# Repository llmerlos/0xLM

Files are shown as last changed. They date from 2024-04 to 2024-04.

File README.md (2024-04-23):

# PICCTRL - 0xLM
## 3x6 + 3 Split Ortholinear Keyboard with on board MCU
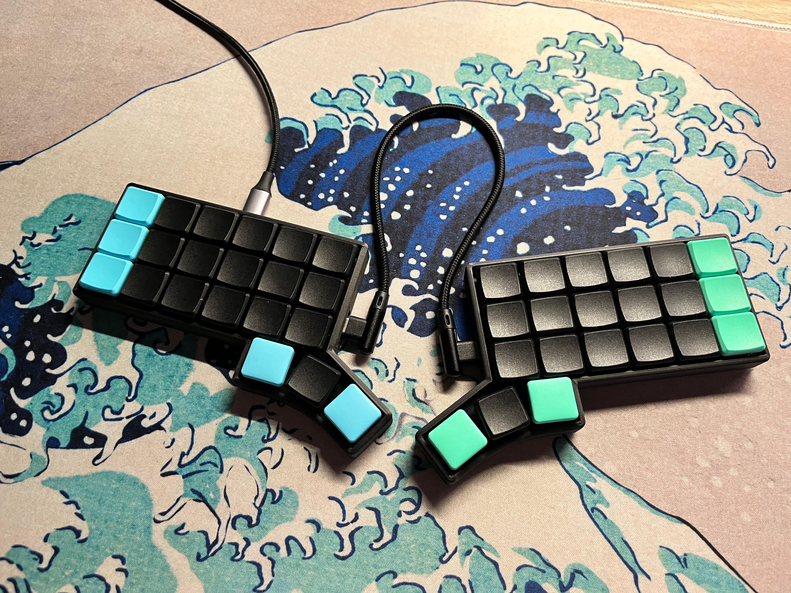
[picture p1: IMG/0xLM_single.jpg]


## Why?
I wanted to make a compact keyboard by using the minimum surface for the keys with all the components underneath them while no increasing the height of the overall keyboard.

## Characteristics:
* CH559L [FAK](https://github.com/semickolon/fak) powered.
* Direct pin with ESD and over-current protection [[Schematic]](https://github.com/llmerlos/0xLM/blob/main/PCB/pdf/Board.pdf).
* [3D Printed Case](https://github.com/llmerlos/0xLM/tree/main/CASE).
* PCBA ready* (See Known Issues). 
* Choc V1 spacing.

## Pics
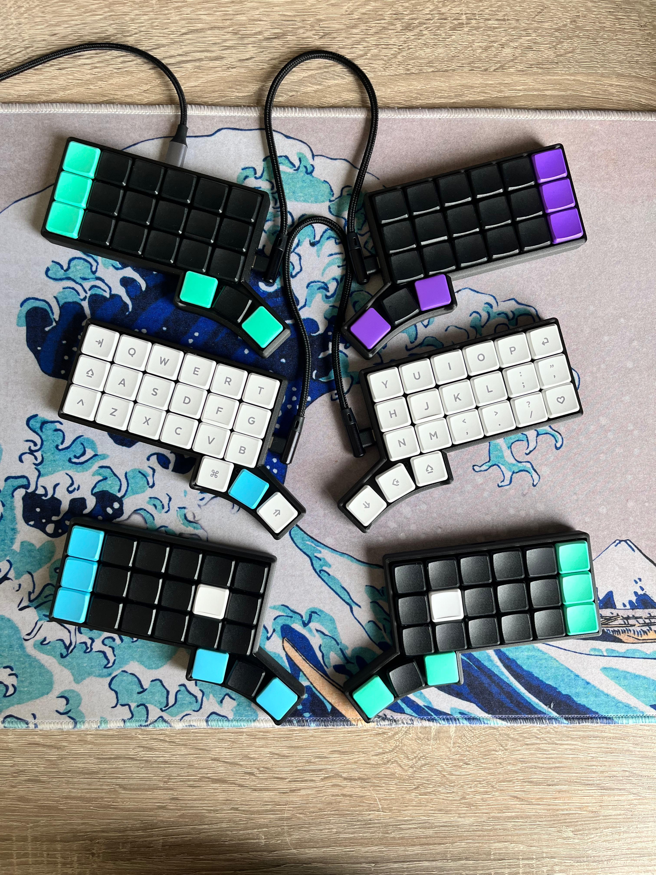
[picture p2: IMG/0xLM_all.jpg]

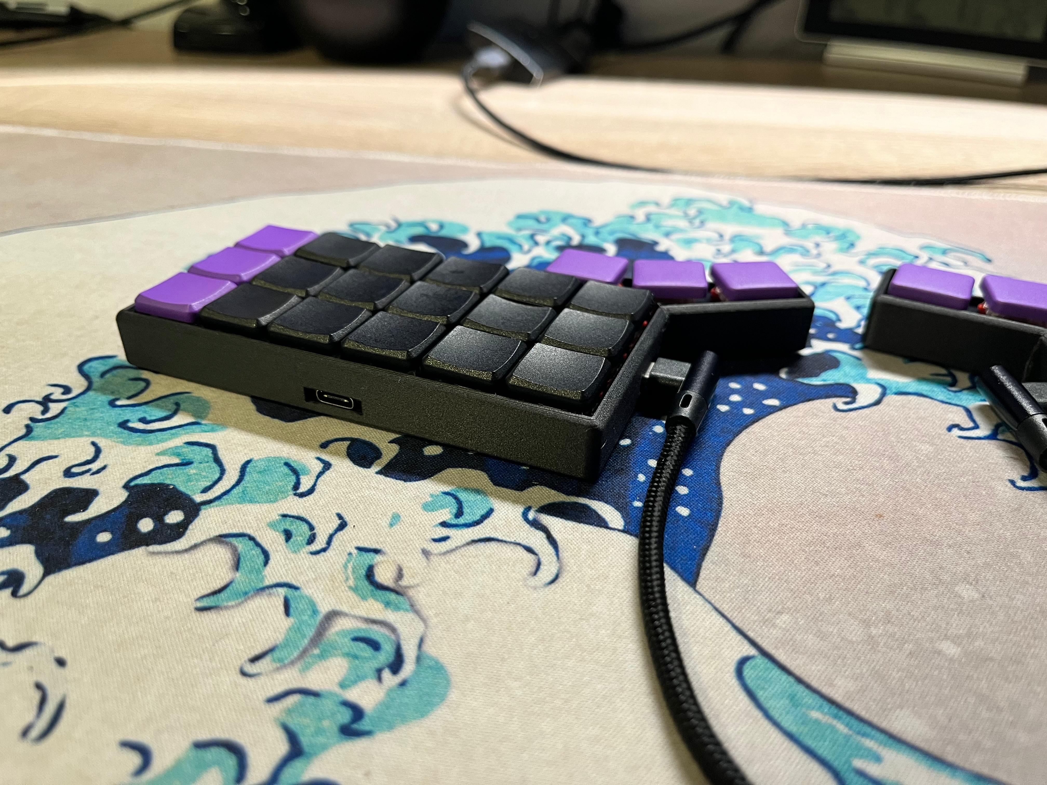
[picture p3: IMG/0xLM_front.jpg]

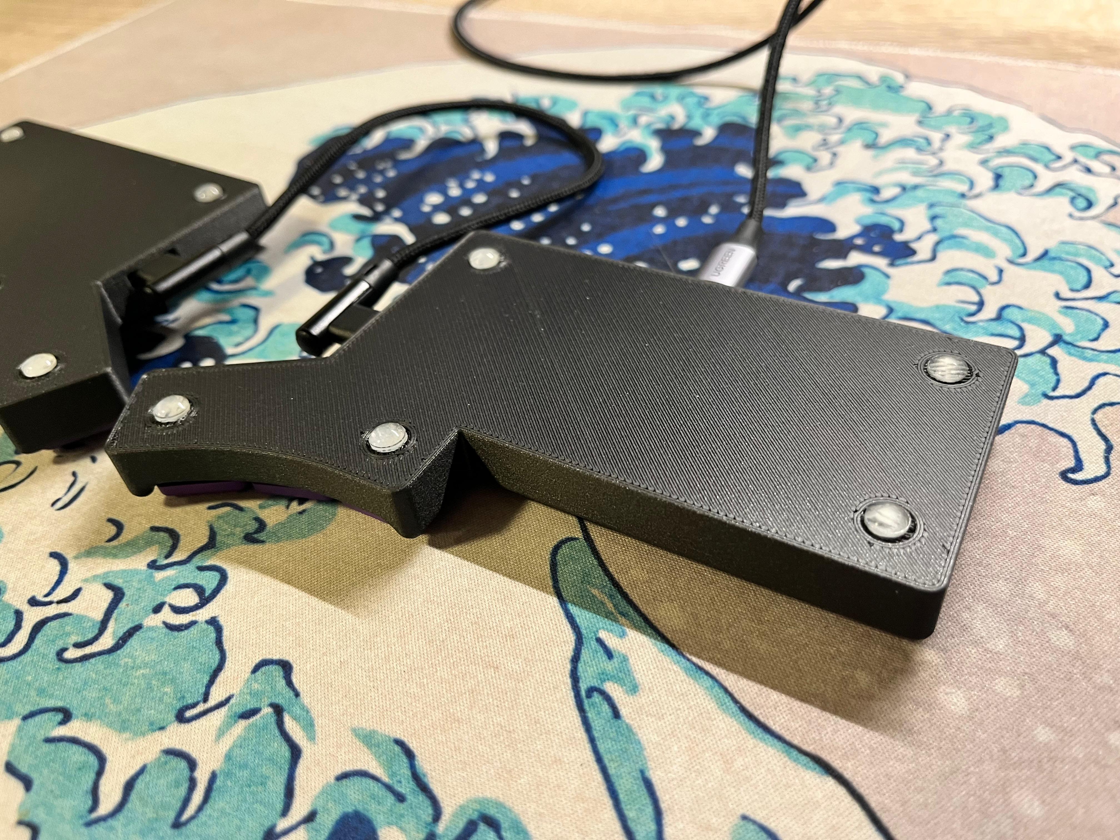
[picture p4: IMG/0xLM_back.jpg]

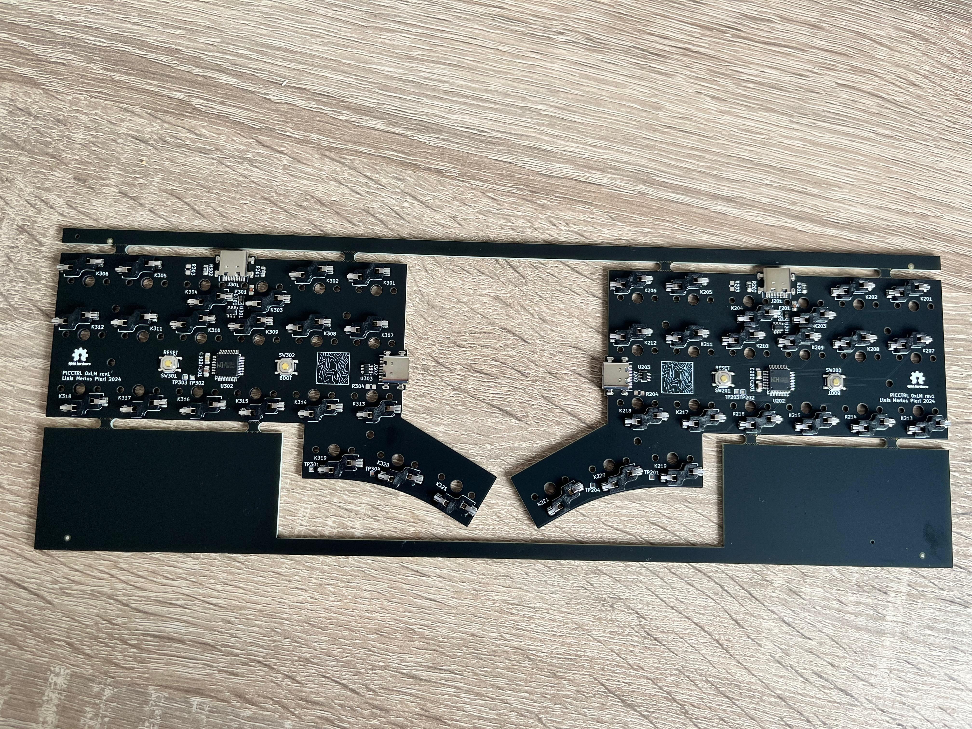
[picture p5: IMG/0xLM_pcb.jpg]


## Known Issues:
* USB part is a little bit missplaced and requires triming the legs (for a fee in JLCPCB).
* USB part is for 0.8mm PCB instead of 1.6mm PCB.
* BOOT silkscreen rotated 180 degrees on the right PCB.

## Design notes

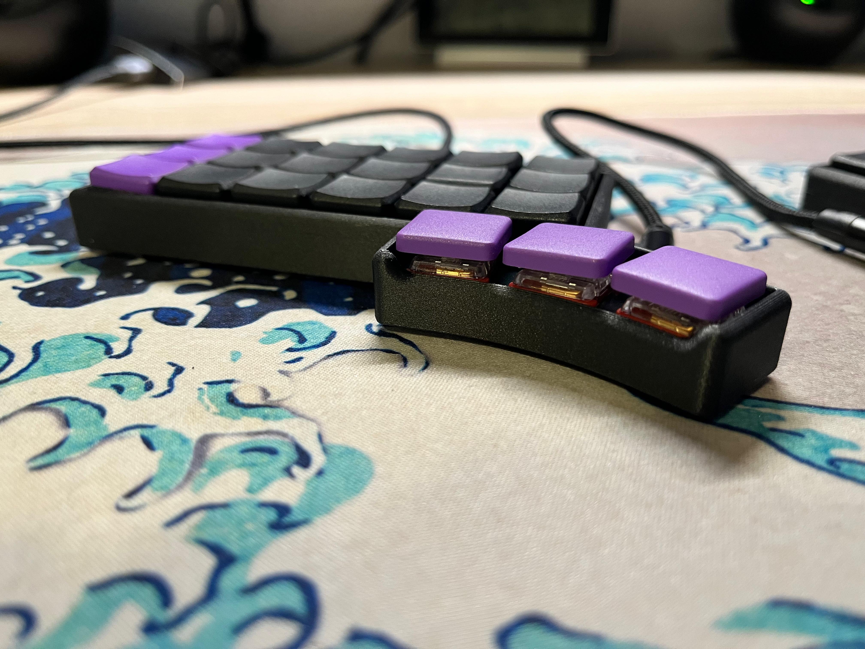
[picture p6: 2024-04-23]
IMG/0xLM_case.jpg

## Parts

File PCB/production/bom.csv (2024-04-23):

Designator | Footprint | Quantity | Value | LCSC Part #
_8, _7, _6, _5, _4, _3, _2, |  | 8
C201, C301 | 0805 | 2 | 3.3uF
C202, C302 | 0805 | 2 | 100nF
D201, D301 | D_SOD-323 | 2 | PMEG2010EA | C193668
F201, F301 | 0805 | 2 | 500mA | C311055
J201, J202, J301, J302 | TYPE-C-31-M-14 | 4 | TYPE-C-31-M-14 | C223907
K201, K202, K203, K204, K205, K206, K207, K208, K209, K210, K211, K212, K213, K214, K215, K216, K217, K218, K219, K220, K221, K301, K302, K303, K304, K305, K306, K307, K308, K309, K310, K311, K312, K313, K314, K315, K316, K317, K318, K319, K320, K321 | SW_Hotswap_Kailh_Choc_V1_1.00u | 42 | CPG135001S30 | C5333465
R201, R202, R301, R302 | 0805 | 4 | 5.1k
SW201, SW202, SW301, SW302 | SW_Push_1P1T_XKB_TS-1187A | 4 | TS-1187A-B-A-B
U201, U203, U301, U303 | SOT-23-6 | 4 | USBLC6-2SC6
U202, U302 | LQFP-48_7x7mm_P0.5mm | 2 | CH559L
mouse-bite-3mm-slot_8, mouse-bite-3mm-slot_7, mouse-bite-3mm-slot_6, mouse-bite-3mm-slot_5, mouse-bite-3mm-slot_4, mouse-bite-3mm-slot_3, mouse-bite-3mm-slot_2, mouse-bite-3mm-slot | mouse-bite-3mm-slot | 8 | VAL**

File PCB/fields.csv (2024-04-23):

Refs | Datasheet | Description | Footprint | JLCPCB Part # | JLCPCB Position Offset | JLCPCB Rotation Offset | Value
C201 | ~ | Unpolarized capacitor | Capacitor_SMD:C_0805_2012Metric_Pad1.18x1.45mm_HandSolder |  |  |  | 3.3uF
C202 | ~ | Unpolarized capacitor | Capacitor_SMD:C_0805_2012Metric_Pad1.18x1.45mm_HandSolder |  |  |  | 100nF
D201 | ~ | Schottky diode | Diode_SMD:D_SOD-323 |  |  |  | PMEG2010EA
F201 | ~ | Resettable fuse, polymeric positive temperature coefficient | Fuse:Fuse_0805_2012Metric_Pad1.15x1.40mm_HandSolder |  |  |  | 500mA
J301 | https://www.usb.org/sites/default/files/documents/usb_type-c.zip | USB 2.0-only 16P Type-C Receptacle connector | picctrl:TYPE-C-31-M-14 |  |  |  | TYPE-610-1.6-T3
J302 | https://www.usb.org/sites/default/files/documents/usb_type-c.zip | USB 2.0-only 16P Type-C Receptacle connector | picctrl:TYPE-C-31-M-14 |  |  |  | TYPE-610-1.6-T3
K202 | ~ | Push button switch, generic, two pins | picctrl:SW_Hotswap_Kailh_Choc_V1_1.00u |  |  |  | CPG135001S30
K203 | ~ | Push button switch, generic, two pins | picctrl:SW_Hotswap_Kailh_Choc_V1_1.00u |  |  |  | CPG135001S30
K204 | ~ | Push button switch, generic, two pins | picctrl:SW_Hotswap_Kailh_Choc_V1_1.00u |  |  |  | CPG135001S30
K205 | ~ | Push button switch, generic, two pins | picctrl:SW_Hotswap_Kailh_Choc_V1_1.00u |  |  |  | CPG135001S30
K206 | ~ | Push button switch, generic, two pins | picctrl:SW_Hotswap_Kailh_Choc_V1_1.00u |  |  |  | CPG135001S30
K207 | ~ | Push button switch, generic, two pins | picctrl:SW_Hotswap_Kailh_Choc_V1_1.00u |  |  |  | CPG135001S30
K208 | ~ | Push button switch, generic, two pins | picctrl:SW_Hotswap_Kailh_Choc_V1_1.00u |  |  |  | CPG135001S30
K209 | ~ | Push button switch, generic, two pins | picctrl:SW_Hotswap_Kailh_Choc_V1_1.00u |  |  |  | CPG135001S30
K210 | ~ | Push button switch, generic, two pins | picctrl:SW_Hotswap_Kailh_Choc_V1_1.00u |  |  |  | CPG135001S30
K211 | ~ | Push button switch, generic, two pins | picctrl:SW_Hotswap_Kailh_Choc_V1_1.00u |  |  |  | CPG135001S30
K212 | ~ | Push button switch, generic, two pins | picctrl:SW_Hotswap_Kailh_Choc_V1_1.00u |  |  |  | CPG135001S30
K213 | ~ | Push button switch, generic, two pins | picctrl:SW_Hotswap_Kailh_Choc_V1_1.00u |  |  |  | CPG135001S30
K214 | ~ | Push button switch, generic, two pins | picctrl:SW_Hotswap_Kailh_Choc_V1_1.00u |  |  |  | CPG135001S30
K215 | ~ | Push button switch, generic, two pins | picctrl:SW_Hotswap_Kailh_Choc_V1_1.00u |  |  |  | CPG135001S30
K216 | ~ | Push button switch, generic, two pins | picctrl:SW_Hotswap_Kailh_Choc_V1_1.00u |  |  |  | CPG135001S30
K217 | ~ | Push button switch, generic, two pins | picctrl:SW_Hotswap_Kailh_Choc_V1_1.00u |  |  |  | CPG135001S30
K218 | ~ | Push button switch, generic, two pins | picctrl:SW_Hotswap_Kailh_Choc_V1_1.00u |  |  |  | CPG135001S30
K219 | ~ | Push button switch, generic, two pins | picctrl:SW_Hotswap_Kailh_Choc_V1_1.00u |  |  |  | CPG135001S30
K220 | ~ | Push button switch, generic, two pins | picctrl:SW_Hotswap_Kailh_Choc_V1_1.00u |  |  |  | CPG135001S30
K221 | ~ | Push button switch, generic, two pins | picctrl:SW_Hotswap_Kailh_Choc_V1_1.00u |  |  |  | CPG135001S30
K301 | ~ | Push button switch, generic, two pins | picctrl:SW_Hotswap_Kailh_Choc_V1_1.00u | C5333465 | -2.5,-4.85 | 180 | CPG135001S30
R301 | ~ | Resistor | Resistor_SMD:R_0805_2012Metric_Pad1.20x1.40mm_HandSolder |  |  |  | 5.1k
R302 | ~ | Resistor | Resistor_SMD:R_0805_2012Metric_Pad1.20x1.40mm_HandSolder |  |  |  | 5.1k
R303 | ~ | Resistor | Resistor_SMD:R_0805_2012Metric_Pad1.20x1.40mm_HandSolder |  |  |  | DNP
R305 | ~ | Resistor | Resistor_SMD:R_0805_2012Metric_Pad1.20x1.40mm_HandSolder |  |  |  | DNP
SW301 | ~ | Push button switch, generic, two pins | Button_Switch_SMD:SW_Push_1P1T_XKB_TS-1187A |  |  |  | TS-1187A-B-A-B
SW302 | ~ | Push button switch, generic, two pins | Button_Switch_SMD:SW_Push_1P1T_XKB_TS-1187A |  |  |  | TS-1187A-B-A-B
U202 | https://www.wch-ic.com/products/CH32X035.html |  | Package_QFP:LQFP-48_7x7mm_P0.5mm |  |  |  | CH559L
U301 | https://www.st.com/resource/en/datasheet/usblc6-2.pdf | Very low capacitance ESD protection diode, 2 data-line, SOT-23-6 | Package_TO_SOT_SMD:SOT-23-6 |  |  |  | USBLC6-2SC6
U303 | https://www.st.com/resource/en/datasheet/usblc6-2.pdf | Very low capacitance ESD protection diode, 2 data-line, SOT-23-6 | Package_TO_SOT_SMD:SOT-23-6 |  |  |  | USBLC6-2SC6

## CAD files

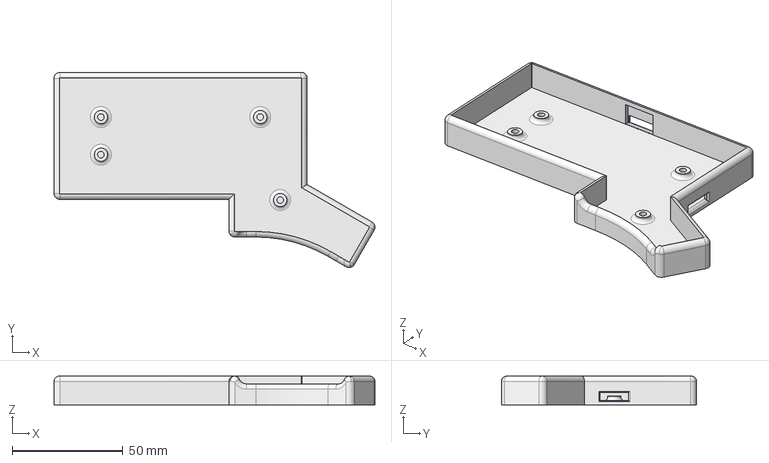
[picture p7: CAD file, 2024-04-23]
CASE/0xLM_case.FCStd
145.1 x 88.2 x 13.0 mm

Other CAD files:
CASE/0xLM_case.stl

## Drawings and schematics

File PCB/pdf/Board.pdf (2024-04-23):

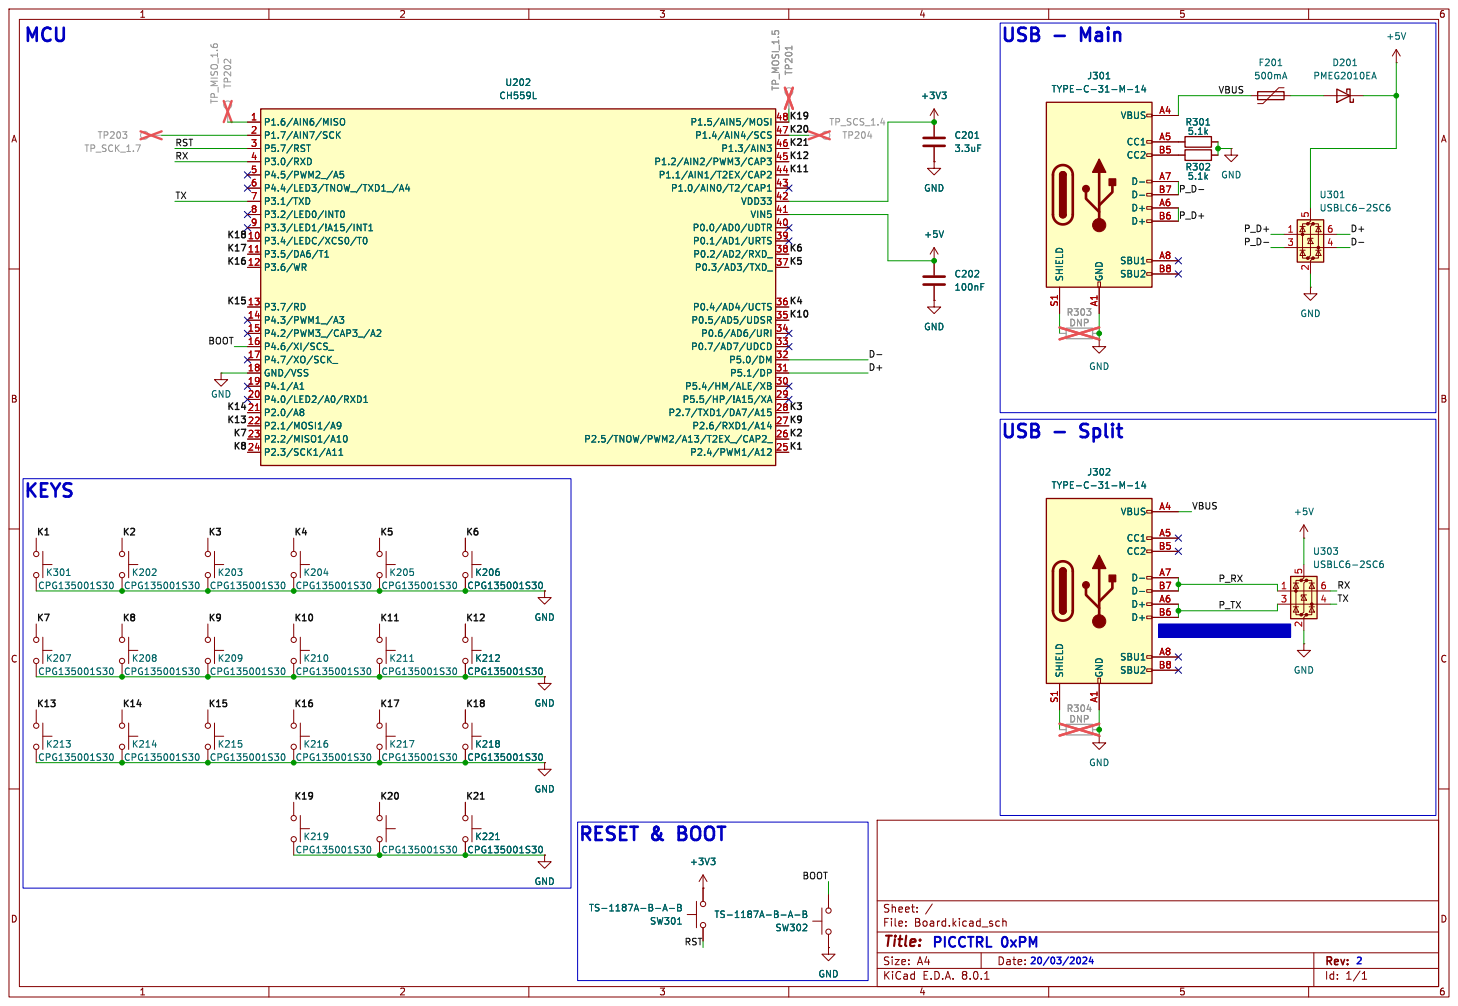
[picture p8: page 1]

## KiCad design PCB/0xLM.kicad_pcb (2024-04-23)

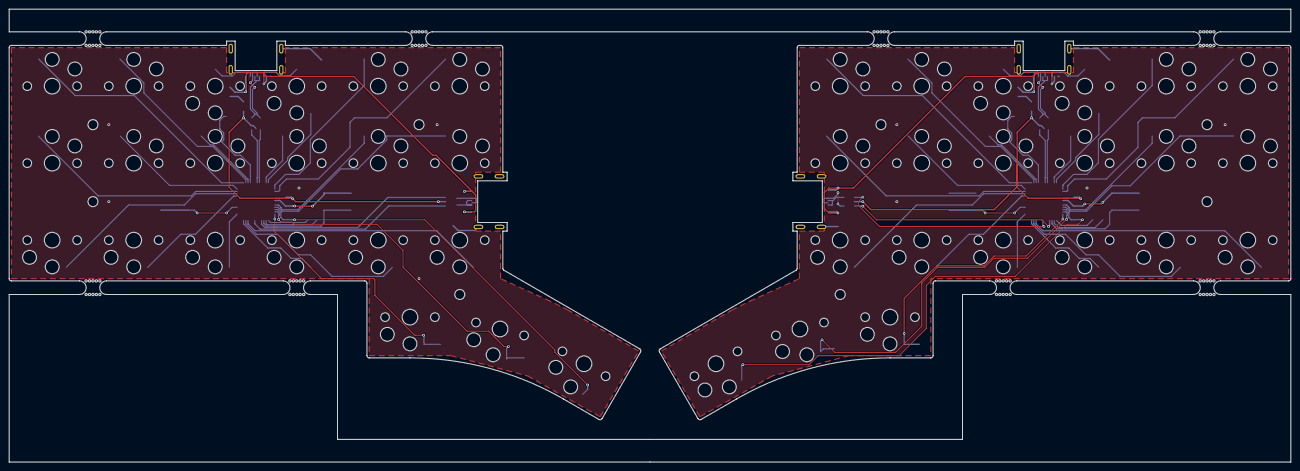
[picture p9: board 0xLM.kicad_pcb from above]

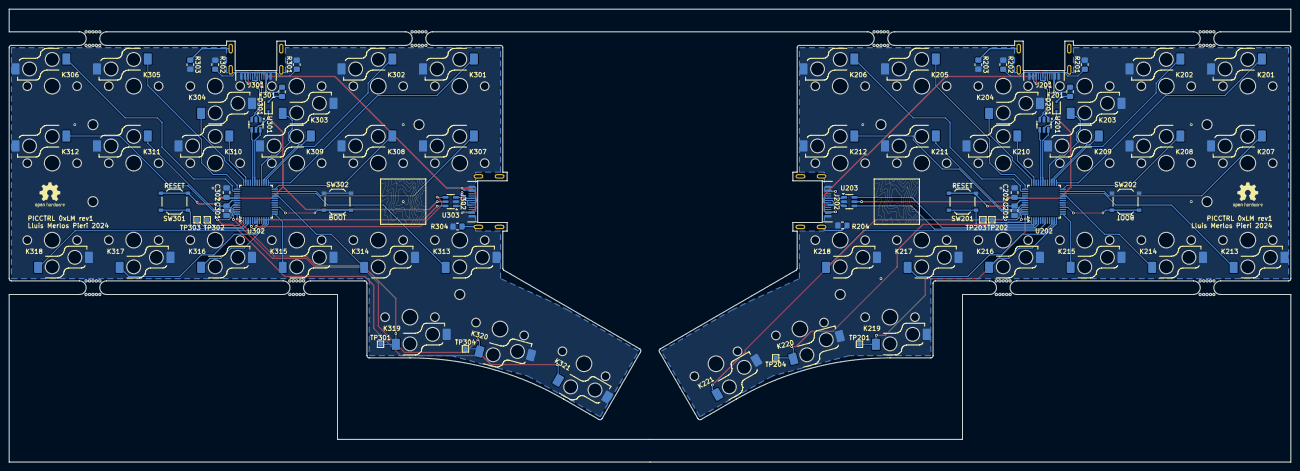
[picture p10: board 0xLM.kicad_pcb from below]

Board: 2 copper layers, 283.0 x 100.0 mm, 88 parts (80 on the bottom side), 81 nets.

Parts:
C201, C301: 3.3uF; C_0805_2012Metric_Pad1.18x1.45mm_HandSolder
C202, C302: 100nF; C_0805_2012Metric_Pad1.18x1.45mm_HandSolder
D201, D301: PMEG2010EA; D_SOD-323
F201, F301: 500mA; Fuse_0805_2012Metric_Pad1.15x1.40mm_HandSolder
J201, J202, J301, J302: TYPE-C-31-M-14
K201, K202, K203, K204, K205, K206, K207, K208, K209, K210, K211, K212, K213, K214, K215, K216, K217, K218, K219, K220, K221, K301, K302, K303, K304, K305, K306, K307, K308, K309, K310, K311, K312, K313, K314, K315, K316, K317, K318, K319, K320, K321: CPG135001S30; SW_Hotswap_Kailh_Choc_V1_1.00u
R201, R202, R301, R302: 5.1k; R_0805_2012Metric_Pad1.20x1.40mm_HandSolder
R203, R204, R303, R304: DNP; R_0805_2012Metric_Pad1.20x1.40mm_HandSolder
SW201, SW202, SW301, SW302: TS-1187A-B-A-B; SW_Push_1P1T_XKB_TS-1187A
TP201, TP301: TP_MOSI_1.5; TestPoint_Pad_1.0x1.0mm
TP202, TP302: TP_MISO_1.6; TestPoint_Pad_1.0x1.0mm
TP203, TP303: TP_SCK_1.7; TestPoint_Pad_1.0x1.0mm
TP204, TP304: TP_SCS_1.4; TestPoint_Pad_1.0x1.0mm
U201, U203, U301, U303: USBLC6-2SC6; SOT-23-6
U202, U302: CH559L; LQFP-48_7x7mm_P0.5mm
mouse-bite-3mm-slot, mouse-bite-3mm-slot#2, mouse-bite-3mm-slot#3, mouse-bite-3mm-slot#4, mouse-bite-3mm-slot#5, mouse-bite-3mm-slot#6, mouse-bite-3mm-slot#7, mouse-bite-3mm-slot#8: VAL**; mouse-bite-3mm-slot

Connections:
+3V3: C201.1, C301.1, SW201.2, SW301.2, U202.42 (VDD33), U302.42 (VDD33)
+5V: C202.1, C302.1, D201.1 (K), D301.1 (K), U201.5 (VBUS), U202.41 (VIN5), U203.5 (VBUS), U301.5 (VBUS), U302.41 (VIN5), U303.5 (VBUS)
/BoardL/BOOT: SW202.2, U202.16 (P4.6/XI/SCS_)
/BoardL/D+: U201.6 (I/O1), U202.31 (P5.1/DP)
/BoardL/D-: U201.4 (I/O2), U202.32 (P5.0/DM)
/BoardL/K1: K201.1, U202.25 (P2.4/PWM1/A12)
/BoardL/K2: K202.1, U202.26 (P2.5/TNOW/PWM2/A13/T2EX_/CAP2_)
/BoardL/K3: K203.1, U202.28 (P2.7/TXD1/DA7/A15)
/BoardL/K4: K204.1, U202.36 (P0.4/AD4/UCTS)
/BoardL/K5: K205.1, U202.37 (P0.3/AD3/TXD_)
/BoardL/K6: K206.1, U202.38 (P0.2/AD2/RXD_)
/BoardL/K7: K207.1, U202.23 (P2.2/MISO1/A10)
/BoardL/K8: K208.1, U202.24 (P2.3/SCK1/A11)
/BoardL/K9: K209.1, U202.27 (P2.6/RXD1/A14)
/BoardL/K10: K210.1, U202.35 (P0.5/AD5/UDSR)
/BoardL/K11: K211.1, U202.44 (P1.1/AIN1/T2EX/CAP2)
/BoardL/K12: K212.1, U202.45 (P1.2/AIN2/PWM3/CAP3)
/BoardL/K13: K213.1, U202.22 (P2.1/MOSI1/A9)
/BoardL/K14: K214.1, U202.21 (P2.0/A8)
/BoardL/K15: K215.1, U202.13 (P3.7/RD)
/BoardL/K16: K216.1, U202.12 (P3.6/WR)
/BoardL/K17: K217.1, U202.11 (P3.5/DA6/T1)
/BoardL/K18: K218.1, U202.10 (P3.4/LEDC/XCS0/T0)
/BoardL/K19: K219.1, TP201.1, U202.48 (P1.5/AIN5/MOSI)
/BoardL/K20: K220.1, TP204.1, U202.47 (P1.4/AIN4/SCS)
/BoardL/K21: K221.1, U202.46 (P1.3/AIN3)
/BoardL/P_D+: J201.A6 (D+), J201.B6 (D+), U201.1 (I/O1)
/BoardL/P_D-: J201.A7 (D-), J201.B7 (D-), U201.3 (I/O2)
/BoardL/P_RX: J202.A7 (D-), J202.B7 (D-), U203.1 (I/O1)
/BoardL/P_TX: J202.A6 (D+), J202.B6 (D+), U203.3 (I/O2)
/BoardL/RST: SW201.1, U202.3 (P5.7/RST)
/BoardL/RX: U202.4 (P3.0/RXD), U203.6 (I/O1)
/BoardL/TX: U202.7 (P3.1/TXD), U203.4 (I/O2)
/BoardL/VBUS: F201.2, J201.A4 (VBUS), J201.A9 (VBUS), J201.B4 (VBUS), J201.B9 (VBUS), J202.A4 (VBUS), J202.A9 (VBUS), J202.B4 (VBUS), J202.B9 (VBUS)
/BoardR/BOOT: SW302.2, U302.16 (P4.6/XI/SCS_)
/BoardR/D+: U301.6 (I/O1), U302.31 (P5.1/DP)
/BoardR/D-: U301.4 (I/O2), U302.32 (P5.0/DM)
/BoardR/K1: K301.1, U302.25 (P2.4/PWM1/A12)
/BoardR/K2: K302.1, U302.26 (P2.5/TNOW/PWM2/A13/T2EX_/CAP2_)
/BoardR/K3: K303.1, U302.28 (P2.7/TXD1/DA7/A15)
/BoardR/K4: K304.1, U302.36 (P0.4/AD4/UCTS)
/BoardR/K5: K305.1, U302.37 (P0.3/AD3/TXD_)
/BoardR/K6: K306.1, U302.38 (P0.2/AD2/RXD_)
/BoardR/K7: K307.1, U302.23 (P2.2/MISO1/A10)
/BoardR/K8: K308.1, U302.24 (P2.3/SCK1/A11)
/BoardR/K9: K309.1, U302.27 (P2.6/RXD1/A14)
/BoardR/K10: K310.1, U302.35 (P0.5/AD5/UDSR)
/BoardR/K11: K311.1, U302.44 (P1.1/AIN1/T2EX/CAP2)
/BoardR/K12: K312.1, U302.45 (P1.2/AIN2/PWM3/CAP3)
/BoardR/K13: K313.1, U302.22 (P2.1/MOSI1/A9)
/BoardR/K14: K314.1, U302.21 (P2.0/A8)
/BoardR/K15: K315.1, U302.13 (P3.7/RD)
/BoardR/K16: K316.1, U302.12 (P3.6/WR)
/BoardR/K17: K317.1, U302.11 (P3.5/DA6/T1)
/BoardR/K18: K318.1, U302.10 (P3.4/LEDC/XCS0/T0)
/BoardR/K19: K319.1, TP301.1, U302.48 (P1.5/AIN5/MOSI)
/BoardR/K20: K320.1, TP304.1, U302.47 (P1.4/AIN4/SCS)
/BoardR/K21: K321.1, U302.46 (P1.3/AIN3)
/BoardR/P_D+: J301.A6 (D+), J301.B6 (D+), U301.1 (I/O1)
/BoardR/P_D-: J301.A7 (D-), J301.B7 (D-), U301.3 (I/O2)
/BoardR/P_RX: J302.A7 (D-), J302.B7 (D-), U303.1 (I/O1)
/BoardR/P_TX: J302.A6 (D+), J302.B6 (D+), U303.3 (I/O2)
/BoardR/RST: SW301.1, U302.3 (P5.7/RST)
/BoardR/RX: U302.4 (P3.0/RXD), U303.6 (I/O1)
/BoardR/TX: U302.7 (P3.1/TXD), U303.4 (I/O2)
/BoardR/VBUS: F301.2, J301.A4 (VBUS), J301.A9 (VBUS), J301.B4 (VBUS), J301.B9 (VBUS), J302.A4 (VBUS), J302.A9 (VBUS), J302.B4 (VBUS), J302.B9 (VBUS)
GND: C201.2, C202.2, C301.2, C302.2, J201.A1 (GND), J201.A12 (GND), J201.B1 (GND), J201.B12 (GND), J202.A1 (GND), J202.A12 (GND), J202.B1 (GND), J202.B12 (GND), J301.A1 (GND), J301.A12 (GND), J301.B1 (GND), J301.B12 (GND), J302.A1 (GND), J302.A12 (GND), J302.B1 (GND), J302.B12 (GND), K201.2, K202.2, K203.2, K204.2, K205.2, K206.2, K207.2, K208.2, K209.2, K210.2, K211.2, K212.2, K213.2, K214.2, K215.2, K216.2, K217.2, K218.2, K219.2, K220.2, K221.2, K301.2, K302.2, K303.2, K304.2, K305.2, K306.2, K307.2, K308.2, K309.2, K310.2, K311.2, K312.2, K313.2, K314.2, K315.2, K316.2, K317.2, K318.2, K319.2, K320.2, K321.2, R201.2, R202.1, R203.2, R204.2, R301.2, R302.1, R303.2, R304.2, SW202.1, SW302.1, U201.2 (GND), U202.18 (GND/VSS), U203.2 (GND), U301.2 (GND), U302.18 (GND/VSS), U303.2 (GND)
unnamed: D201.2 (A), F201.1
unnamed: D301.2 (A), F301.1
unnamed: J201.A5 (CC1), R201.1
unnamed: J201.B5 (CC2), R202.2
unnamed: J201.S1 (SHIELD), R203.1
unnamed: J202.S1 (SHIELD), R204.1
unnamed: J301.A5 (CC1), R301.1
unnamed: J301.B5 (CC2), R302.2
unnamed: J301.S1 (SHIELD), R303.1
unnamed: J302.S1 (SHIELD), R304.1
unnamed: TP202.1, U202.1 (P1.6/AIN6/MISO)
unnamed: TP203.1, U202.2 (P1.7/AIN7/SCK)
unnamed: TP302.1, U302.1 (P1.6/AIN6/MISO)
unnamed: TP303.1, U302.2 (P1.7/AIN7/SCK)
